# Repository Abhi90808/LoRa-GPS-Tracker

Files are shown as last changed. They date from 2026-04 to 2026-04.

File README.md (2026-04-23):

# LoRa GPS Tracker

A custom PCB GPS tracker using LoRa wireless communication for long-range, low-power asset tracking. Designed in KiCad 8, combining a GPS module and LoRa transceiver for remote location reporting.

---

## Features
- LoRa long-range wireless (up to 10km line-of-sight)
- GPS module integration (NEO-6M or compatible)
- Ultra-low power design for battery operation
- SMA or u.FL antenna connector
- Compatible with LoRaWAN / peer-to-peer

## Specifications

| Parameter | Value |
|---|---|
| LoRa Module | Ra-02 / RFM95W (SX1278) |
| GPS Module | NEO-6M / NEO-8M |
| Frequency | 433MHz / 868MHz / 915MHz |
| Range | Up to 10km (line of sight) |
| Supply Voltage | 3.3V |
| Interface | SPI (LoRa), UART (GPS) |
| PCB Layers | 2 |
| Designed With | KiCad 8 |

## Project Structure

```
├── Schematic/       # KiCad schematic (.kicad_sch, PDF)
├── PCB/             # PCB layout (.kicad_pcb, .kicad_pro)
├── Gerbers/         # Fabrication files
├── BOM/             # Bill of materials (CSV)
├── 3D/              # 3D model (.step)
└── Images/          # PCB renders and schematic screenshots
```

## How It Works

The GPS module sends NMEA sentences via UART to the MCU. The MCU parses the latitude/longitude and transmits it as a LoRa packet. A receiver node (another LoRa module or a LoRaWAN gateway) picks up the packet and logs or displays the location.

## Bill of Materials (Summary)

| Component | Value | Qty |
|---|---|-----|
| LoRa Module | Ra-02 / RFM95W | 1 |
| GPS Module | NEO-6M | 1 |
| MCU | ATmega328p / STM32 | 1 |
| Voltage Regulator | AMS1117-3.3V | 1 |
| Antenna Connector | SMA / u.FL | 1 |

## Fabrication

Gerber files are in `/Gerbers`, ready for JLCPCB, PCBWay, or similar.

## License

This project is licensed under the [CERN Open Hardware Licence Version 2 - Strongly Reciprocal (CERN OHL-S v2)](https://ohwr.org/cern_ohl_s_v2.txt).

## Author

**Abhi90808** — [GitHub Profile](https://github.com/Abhi90808)

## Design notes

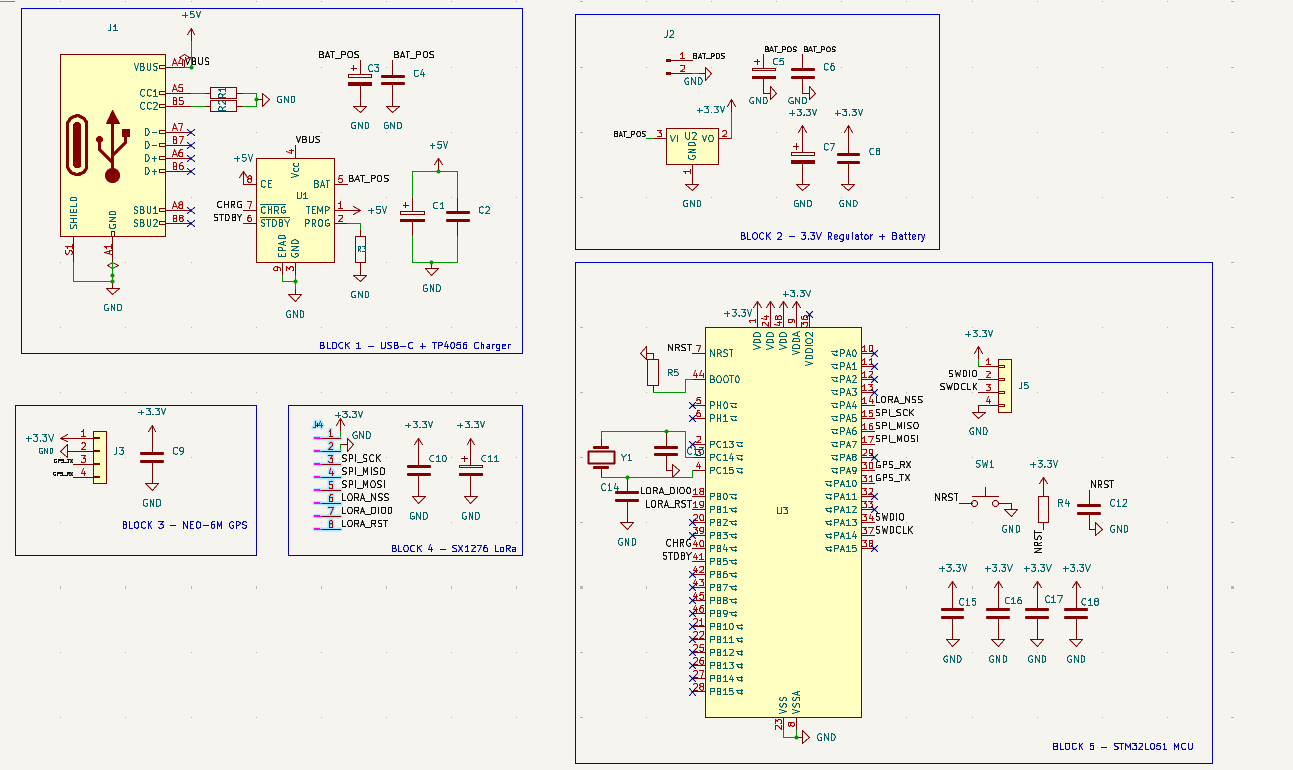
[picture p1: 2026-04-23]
Screenshot 2026-04-20 081845.png

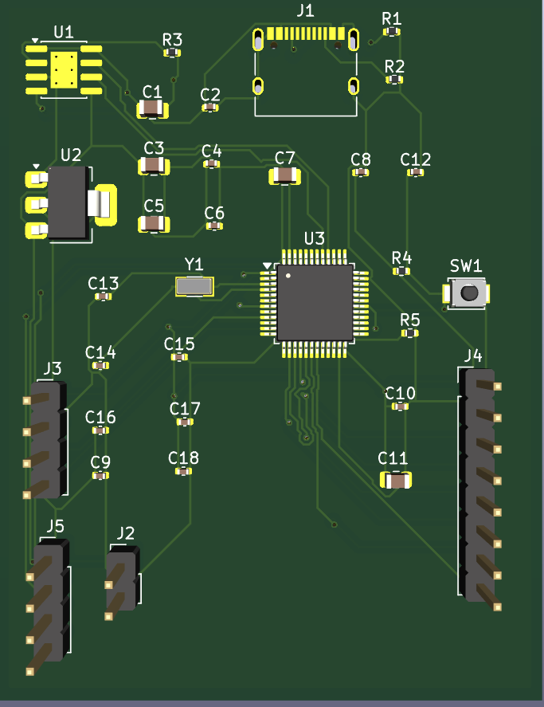
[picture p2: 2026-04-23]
Screenshot 2026-04-20 081927.png

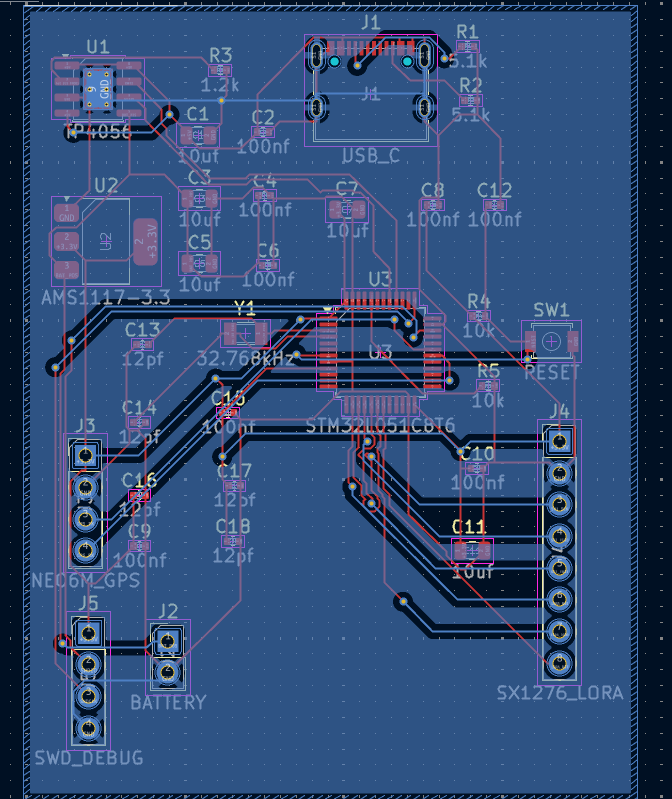
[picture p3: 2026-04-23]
Screenshot 2026-04-20 081901.png

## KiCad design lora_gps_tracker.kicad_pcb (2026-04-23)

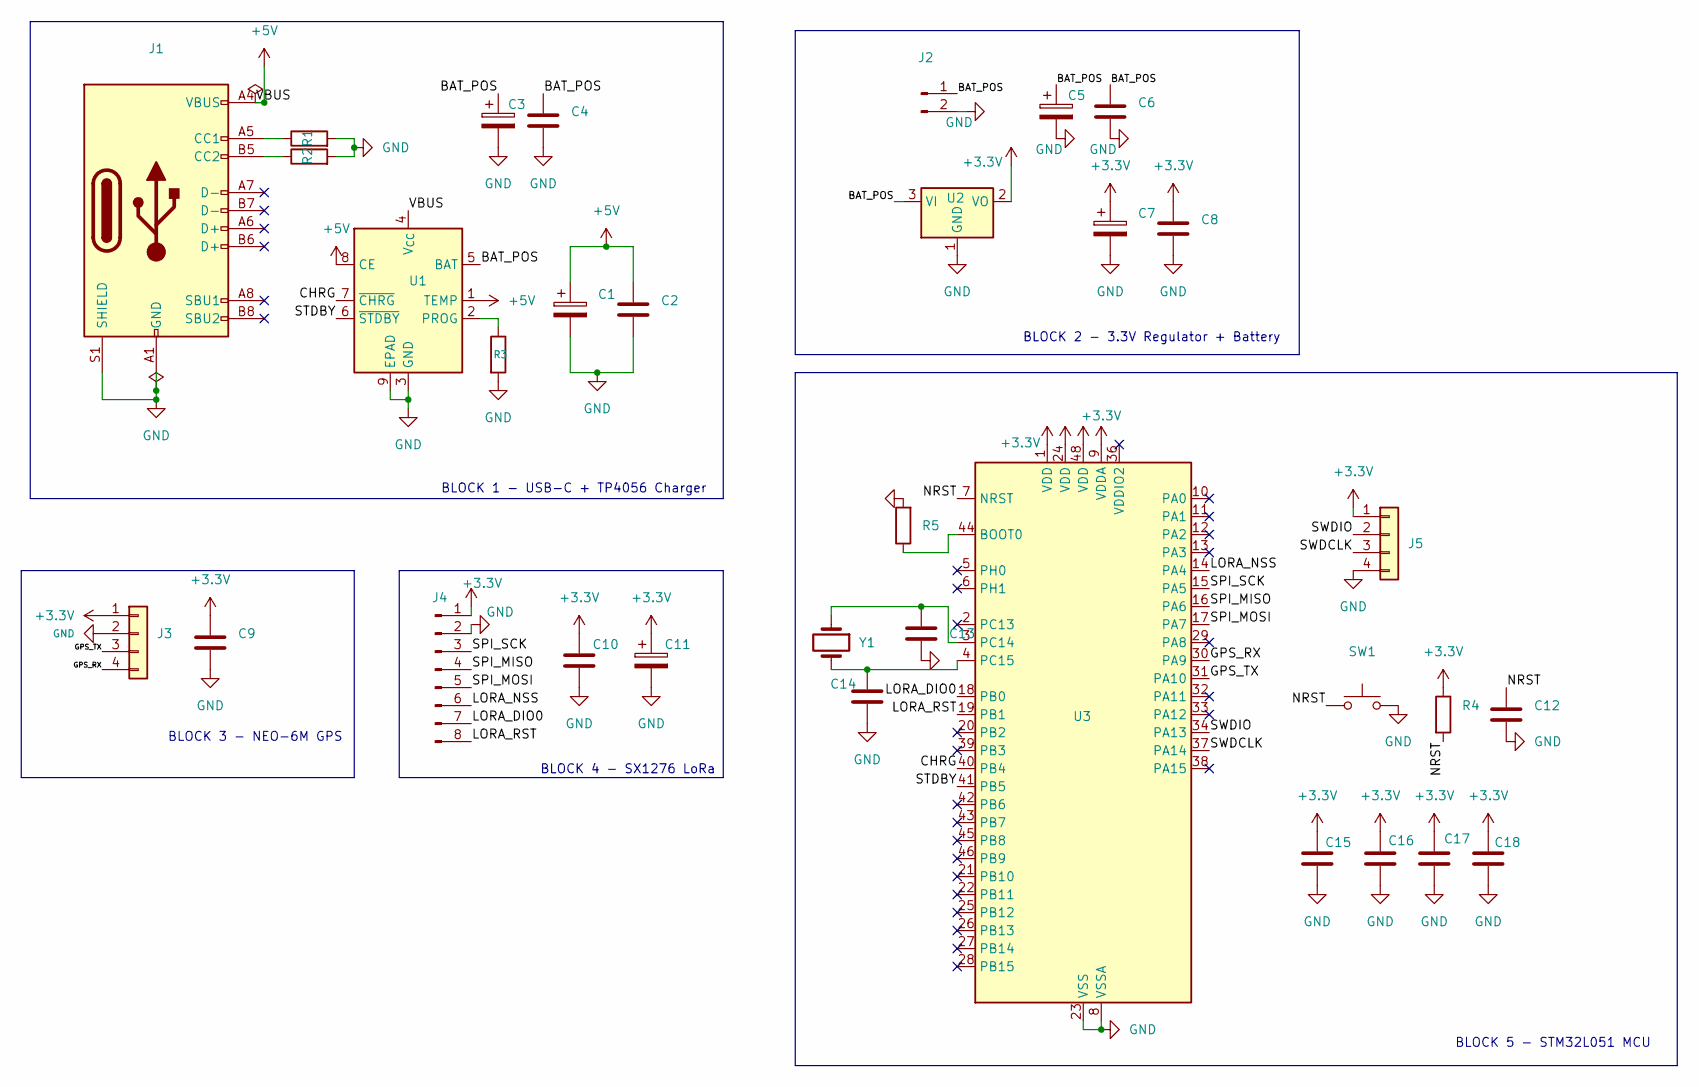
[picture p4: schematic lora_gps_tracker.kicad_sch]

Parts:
C1, C3, C5, C7, C11: 10uf; C_0805_2012Metric
C2, C4, C6, C8, C9, C10, C12, C15: 100nf; C_0402_1005Metric
C13, C14, C16, C17, C18: 12pf; C_0402_1005Metric
J1: USB_C; USB_C_Receptacle_XKB_U262-16XN-4BVC11
J2: BATTERY; PinHeader_1x02_P2.54mm_Vertical
J3: NEO6M_GPS; PinHeader_1x04_P2.54mm_Vertical
J4: SX1276_LORA; PinHeader_1x08_P2.54mm_Vertical
J5: SWD_DEBUG; PinHeader_1x04_P2.54mm_Vertical
R1, R2: 5.1k; R_0402_1005Metric
R3: 1.2k; R_0402_1005Metric
R4, R5: 10k; R_0402_1005Metric
SW1: RESET; SW_SPST_B3U-1000P
U1: TP4056; SOIC-8-1EP_3.9x4.9mm_P1.27mm_EP2.41x3.3mm_ThermalVias
U2: AMS1117-3.3; SOT-223-3_TabPin2
U3: STM32L051C8T6; LQFP-48_7x7mm_P0.5mm
Y1: 32.768kHz; Crystal_SMD_3215-2Pin_3.2x1.5mm

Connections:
+3.3V: C7.1, C8.1, C9.1, C10.1, C11.1, C15.1, C16.1, C17.1, C18.1, J3.1, J4.1, J5.1, R4.1, U2.2 (VO), U3.1 (VDD), U3.9 (VDDA), U3.24 (VDD), U3.48 (VDD)
+5V: C1.1, C2.1, J1.A4 (VBUS), J1.A9 (VBUS), J1.B4 (VBUS), J1.B9 (VBUS), U1.1 (TEMP), U1.4 (V_{CC}), U1.8 (CE)
/BAT_POS: C3.1, C4.1, C5.1, C6.1, J2.1, U1.5 (BAT), U2.3 (VI)
/CHRG: U1.7 (~CHRG), U3.40 (PB4)
/GPS_RX: J3.4, U3.30 (PA9)
/GPS_TX: J3.3, U3.31 (PA10)
/LORA_DIO0: J4.7, U3.18 (PB0)
/LORA_NSS: J4.6, U3.14 (PA4)
/LORA_RST: J4.8, U3.19 (PB1)
/NRST: C12.1, R4.2, SW1.1, U3.7 (NRST)
/SPI_MISO: J4.4, U3.16 (PA6)
/SPI_MOSI: J4.5, U3.17 (PA7)
/SPI_SCK: J4.3, U3.15 (PA5)
/STDBY: U1.6 (~STDBY), U3.41 (PB5)
/SWDCLK: J5.3, U3.37 (PA14)
/SWDIO: J5.2, U3.34 (PA13)
GND: C1.2, C2.2, C3.2, C4.2, C5.2, C6.2, C7.2, C8.2, C9.2, C10.2, C11.2, C12.2, C13.1, C14.2, C15.2, C16.2, C17.2, C18.2, J1.A1 (GND), J1.A12 (GND), J1.B1 (GND), J1.B12 (GND), J1.S1 (SHIELD), J2.2, J3.2, J4.2, J5.4, R1.2, R2.2, R3.2, R5.2, SW1.2, U1.3 (GND), U1.9 (EPAD), U2.1 (GND), U3.8 (VSSA), U3.23 (VSS), U3.35 (VSS), U3.47 (VSS)
unnamed: J1.A5 (CC1), R1.1
unnamed: J1.B5 (CC2), R2.1
unnamed: R3.1, U1.2 (PROG)
unnamed: R5.1, U3.44 (BOOT0)
unnamed: C13.2, U3.3 (PC14), Y1.1
unnamed: C14.1, U3.4 (PC15), Y1.2

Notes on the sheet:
BLOCK 3 - NEO-6M GPS
BLOCK 1 - USB-C + TP4056 Charger
BLOCK 4 - SX1276 LoRa
BLOCK 5 - STM32L051 MCU
BLOCK 2 - 3.3V Regulator + Battery

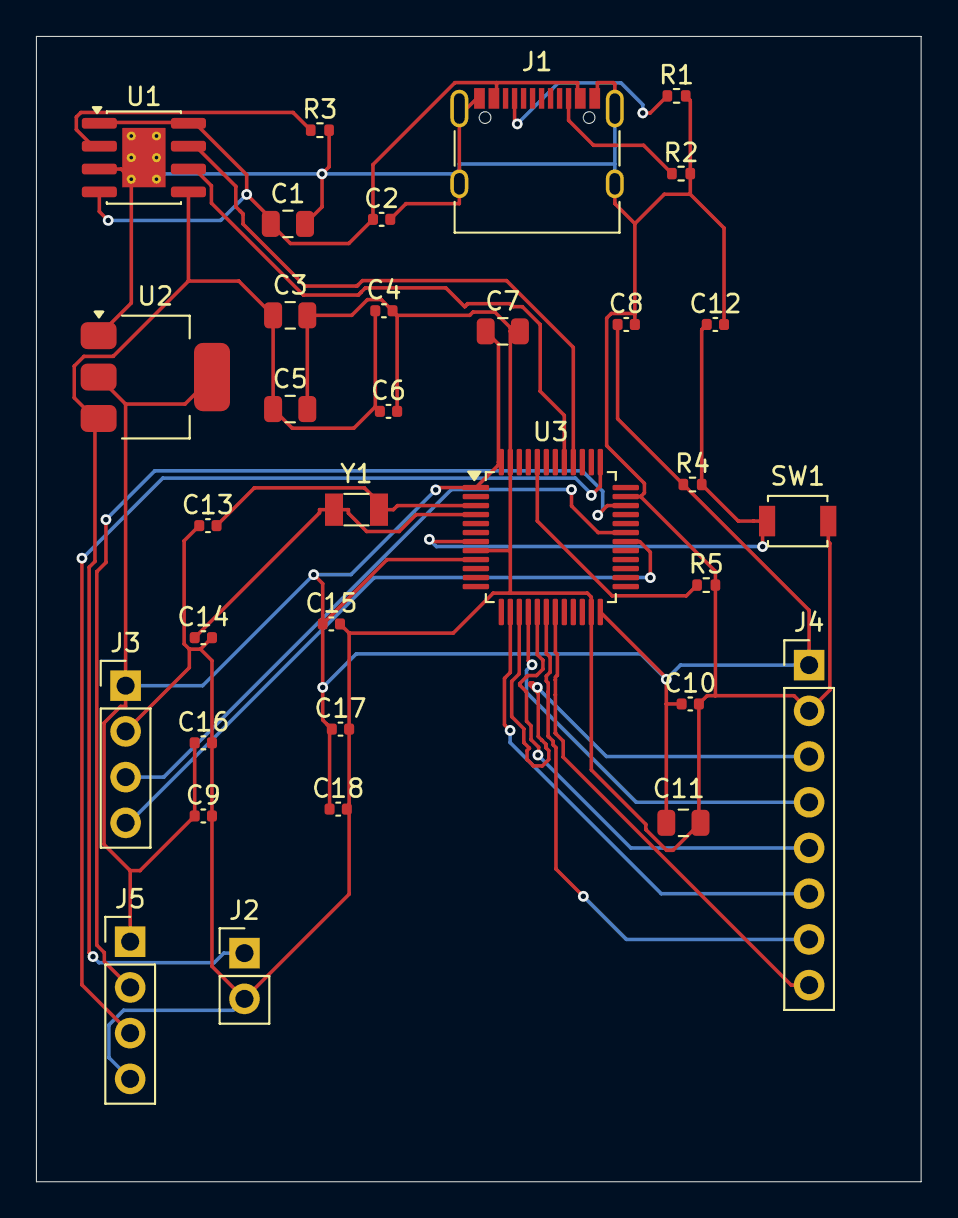
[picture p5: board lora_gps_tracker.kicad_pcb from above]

Board: 2 copper layers, 49.1 x 63.6 mm, 33 parts (0 on the bottom side), 23 nets.
